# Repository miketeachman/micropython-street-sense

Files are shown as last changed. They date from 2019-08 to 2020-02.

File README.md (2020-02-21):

# Street Sense

Street Sense is a MicroPython based project to build a portable, battery-powered sensor unit to measure: 

- **Air Quality**
    - Ozone
    - NO2 
    - Particulates 
- **Noise Pollution**
- **Environment**
    - Temperature
    - Humidity

## Detailed project documentation:
[Street Sense Project at Hackaday IO](https://hackaday.io/project/162059-street-sense)

## Dependencies
### Hardware 
Lolin D32 Pro  
<https://wiki.wemos.cc/products:d32:d32_pro>
### Micropython
fork of micropython
https://github.com/miketeachman/micropython/tree/esp32-i2s-streetsense-littlevgl
which includes these customizations:
- I2S module to read audio samples from an I2S microphone. [link](https://github.com/miketeachman/micropython/blob/esp32-i2s-streetsense-littlevgl/ports/esp32/machine_i2s.c)
- dba module for calculating dB(A) from a stream of audio samples. [link](https://github.com/miketeachman/micropython/blob/esp32-i2s-streetsense-littlevgl/ports/esp32/moddba.c)  
- i2stools module for efficient copy/pruning of audio samples. [link](https://github.com/miketeachman/micropython/blob/esp32-i2s-streetsense-littlevgl/ports/esp32/modi2stools.c)
- integration of littlevGL graphics library. [link](https://github.com/miketeachman/lv_binding_micropython/tree/lvgl-streetsense)

### MicroPython Modules

| name|link|
|---- | ----- |
|asyn | https://github.com/peterhinch/micropython-async/blob/master/asyn.py  |
|aswitch | https://github.com/peterhinch/micropython-async/blob/master/aswitch.py |
|uasyncio (fast\_io) | https://github.com/peterhinch/micropython-async/tree/master/fast_io  |
|ms\_timer| https://github.com/peterhinch/micropython-async/blob/master/fast_io/ms_timer.py |
|pms5003: | https://github.com/miketeachman/micropython-pms5003-minimal | 
|urtc: | https://github.com/adafruit/Adafruit-uRTC |
|ads1219: | https://github.com/miketeachman/micropython-ads1219|
|si7021:  | https://github.com/chrisbalmer/micropython-si7021|
|mqtt\_as:| https://github.com/kevinkk525/micropython-mqtt/tree/pause_resume|
|logging: | https://github.com/micropython/micropython-lib/tree/master/logging|

### MicroPython Libs
fork of littlevgl graphics library with customizations
https://github.com/miketeachman/lv_binding_micropython/commits/lvgl-streetsense

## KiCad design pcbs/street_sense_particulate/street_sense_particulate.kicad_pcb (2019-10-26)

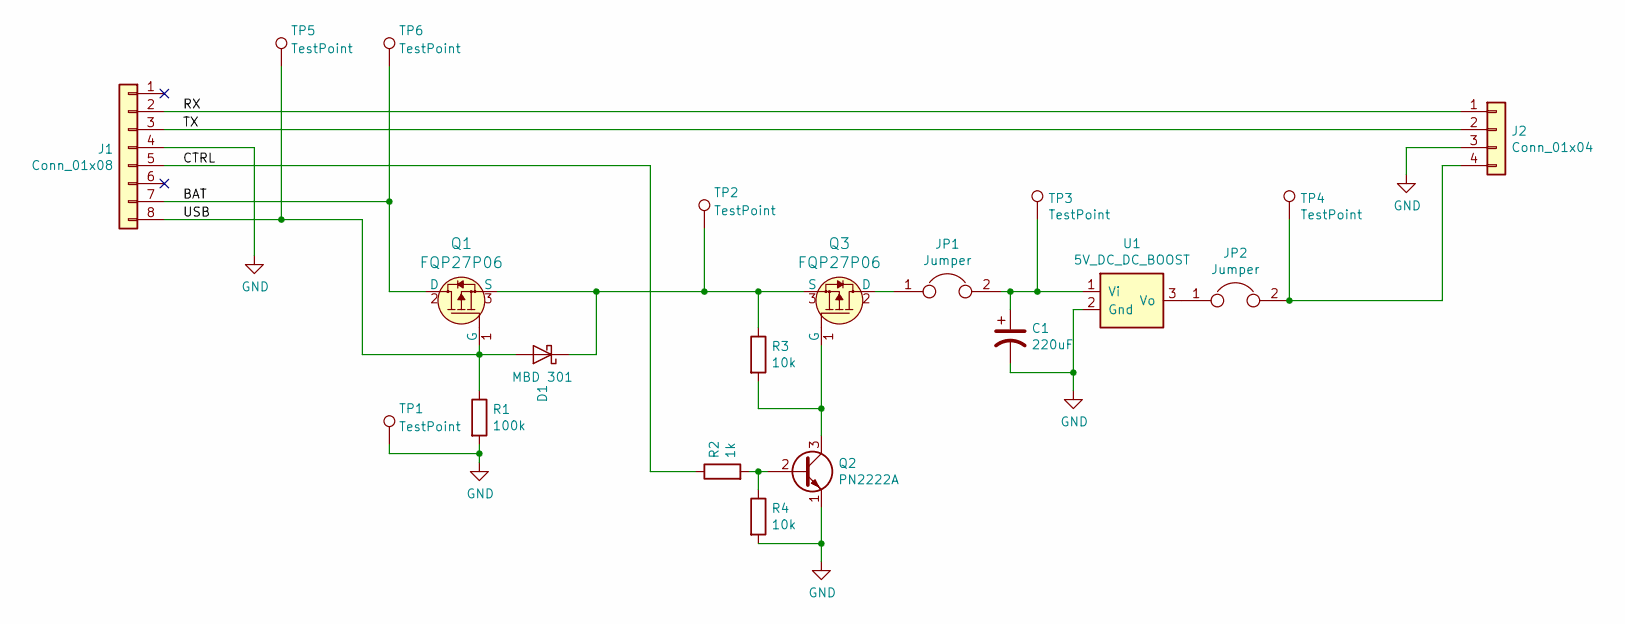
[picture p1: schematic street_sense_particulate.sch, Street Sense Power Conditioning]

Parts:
C1: 220uF; CP_Radial_D5.0mm_P2.50mm
D1: MBD 301; D_A-405_P5.08mm_Vertical_AnodeUp
J1: Conn_01x08; PinHeader_1x08_P2.54mm_Vertical
J2: Conn_01x04; PinHeader_1x04_P2.54mm_Vertical
JP1, JP2: Jumper; SolderJumper-2_P1.3mm_Open_Pad1.0x1.5mm
Q1, Q3: FQP27P06; TO-220-3; MPN FQP27P06; Digi-Key_PN FQP27P06-ND
Q2: PN2222A; TO-92-3_Formed_Leads
R1: 100k; R_Axial_DIN0207_L6.3mm_D2.5mm_P10.16mm_Horizontal
R2: 1k; R_Axial_DIN0207_L6.3mm_D2.5mm_P10.16mm_Horizontal
R3: 10k; R_Axial_DIN0309_L9.0mm_D3.2mm_P12.70mm_Horizontal
R4: 10k; R_Axial_DIN0204_L3.6mm_D1.6mm_P2.54mm_Vertical
TP1, TP2, TP3, TP4, TP5, TP6: TestPoint; TestPoint_Loop_D2.50mm_Drill1.0mm
U1: 5V_DC_DC_BOOST; TO-220-3

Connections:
/BAT: J1.7, Q1.2 (D), TP6.1
/CTRL: J1.5, R2.1
/RX: J1.2, J2.1
/TX: J1.3, J2.2
/USB: D1.2 (A), J1.8, Q1.1 (G), R1.1, TP5.1
GND: C1.2, J1.4, J2.3, Q2.1 (E), R1.2, R4.2, TP1.1, U1.2 (Gnd)
unnamed: C1.1, JP1.2, TP3.1, U1.1 (Vi)
unnamed: D1.1 (K), Q1.3 (S), Q3.3 (S), R3.1, TP2.1
unnamed: J2.4, JP2.2, TP4.1
unnamed: JP1.1, Q3.2 (D)
unnamed: JP2.1, U1.3 (Vo)
unnamed: Q2.2 (B), R2.2, R4.1
unnamed: Q2.3 (C), Q3.1 (G), R3.2

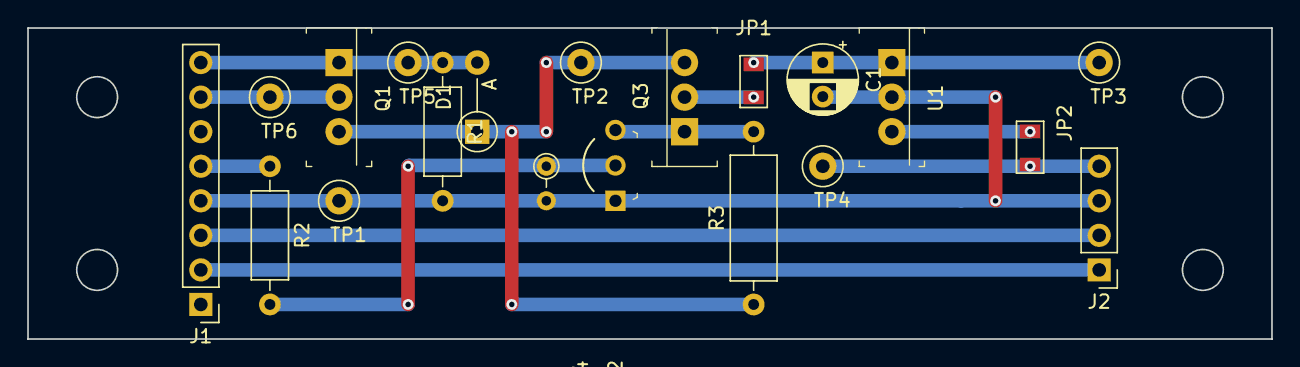
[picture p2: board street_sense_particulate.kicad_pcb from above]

Board: 2 copper layers, 91.4 x 22.9 mm, 20 parts (0 on the bottom side), 13 nets.

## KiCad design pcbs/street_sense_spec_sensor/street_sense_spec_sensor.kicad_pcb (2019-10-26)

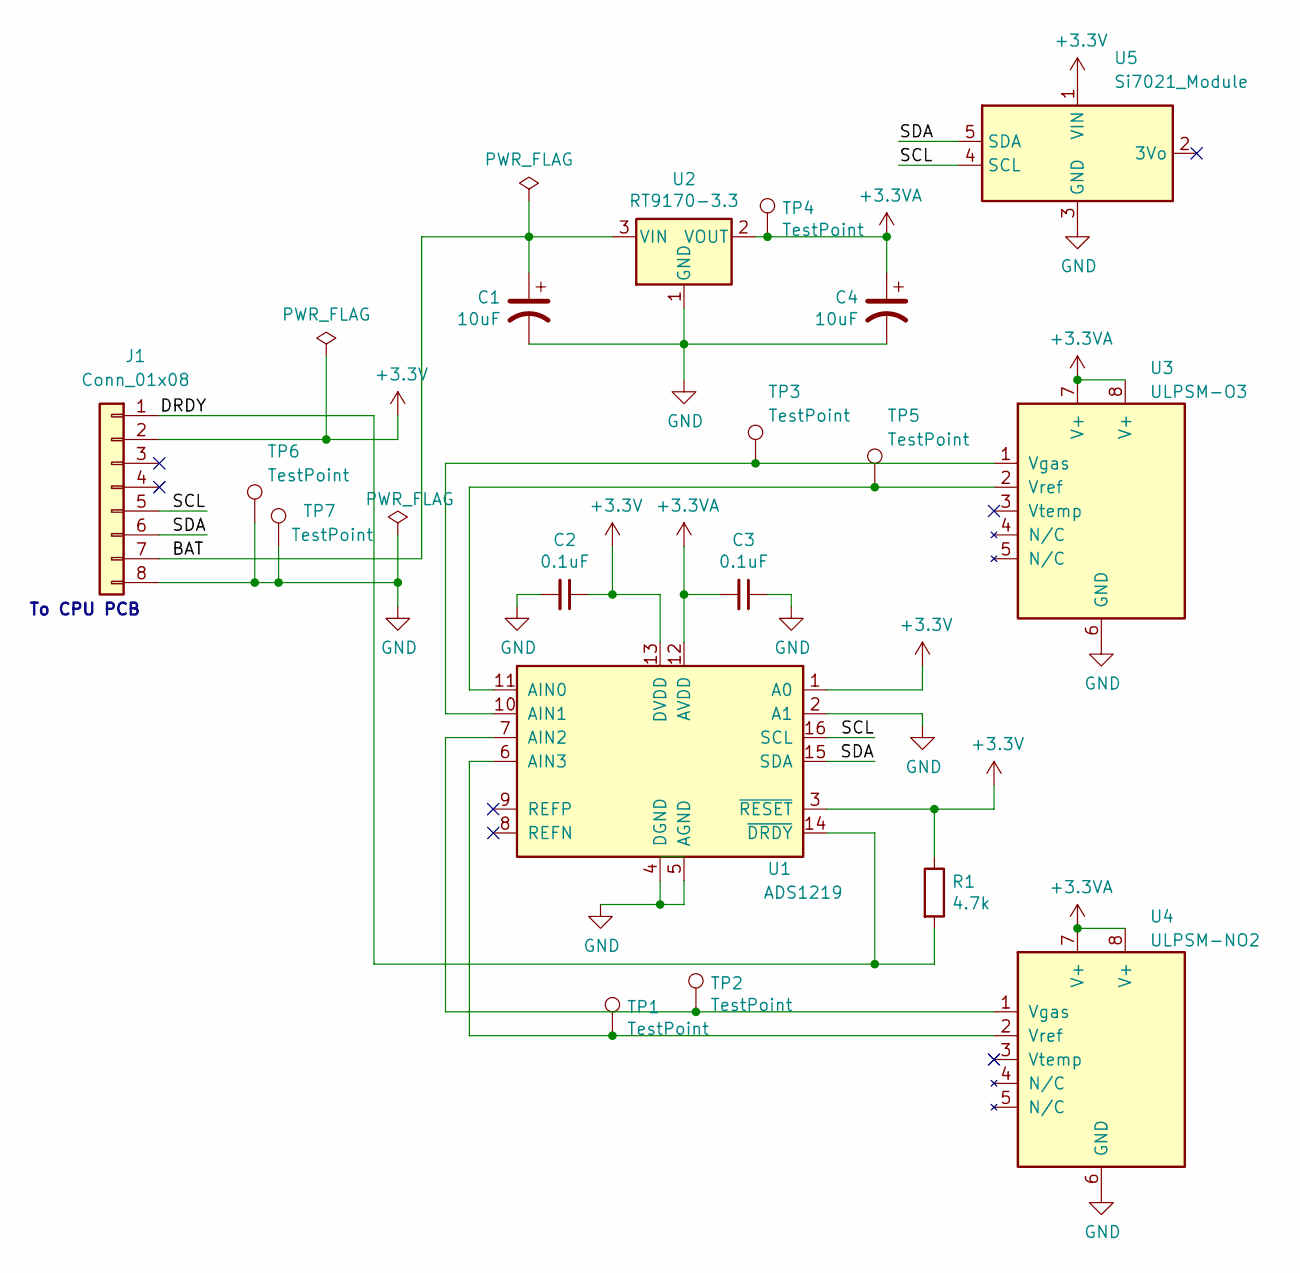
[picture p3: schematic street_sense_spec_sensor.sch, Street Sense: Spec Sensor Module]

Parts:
C1: 10uF; CP_Radial_Tantal_D4.5mm_P2.50mm
C2, C3: 0.1uF; C_Disc_D4.3mm_W1.9mm_P5.00mm
C4: 10uF; CP_Radial_Tantal_D4.5mm_P5.00mm
J1: Conn_01x08; connector_8pin
R1: 4.7k; R_Axial_DIN0204_L3.6mm_D1.6mm_P2.54mm_Vertical
TP1, TP2, TP3, TP4, TP5, TP6, TP7: TestPoint; TestPoint_Loop_D2.50mm_Drill1.0mm
U1: ADS1219; ADS1219_Module
U2: RT9170-3.3; RT9170_Module
U3: ULPSM-O3; Spec_Sensor_ULPSM_Module
U4: ULPSM-NO2; Spec_Sensor_ULPSM_Module
U5: Si7021_Module

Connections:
+3.3VA: C3.2, C4.1, TP4.1, U1.12 (AVDD), U2.2 (VOUT), U3.7 (V+), U3.8 (V+), U4.7 (V+), U4.8 (V+)
+3V3: C2.1, J1.2, R1.1, U1.1 (A0), U1.3 (~RESET), U1.13 (DVDD), U5.1 (VIN)
/BAT: C1.1, J1.7, U2.3 (VIN)
/DRDY: J1.1, R1.2, U1.14 (~DRDY)
/SCL: J1.5, U1.16 (SCL), U5.4 (SCL)
/SDA: J1.6, U1.15 (SDA), U5.5 (SDA)
GND: C1.2, C2.2, C3.1, C4.2, J1.8, TP6.1, TP7.1, U1.2 (A1), U1.4 (DGND), U1.5 (AGND), U2.1 (GND), U3.6 (GND), U4.6 (GND), U5.3 (GND)
unnamed: TP1.1, U1.6 (AIN3), U4.2 (Vref)
unnamed: TP2.1, U1.7 (AIN2), U4.1 (Vgas)
unnamed: TP3.1, U1.10 (AIN1), U3.1 (Vgas)
unnamed: TP5.1, U1.11 (AIN0), U3.2 (Vref)

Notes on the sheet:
To CPU PCB

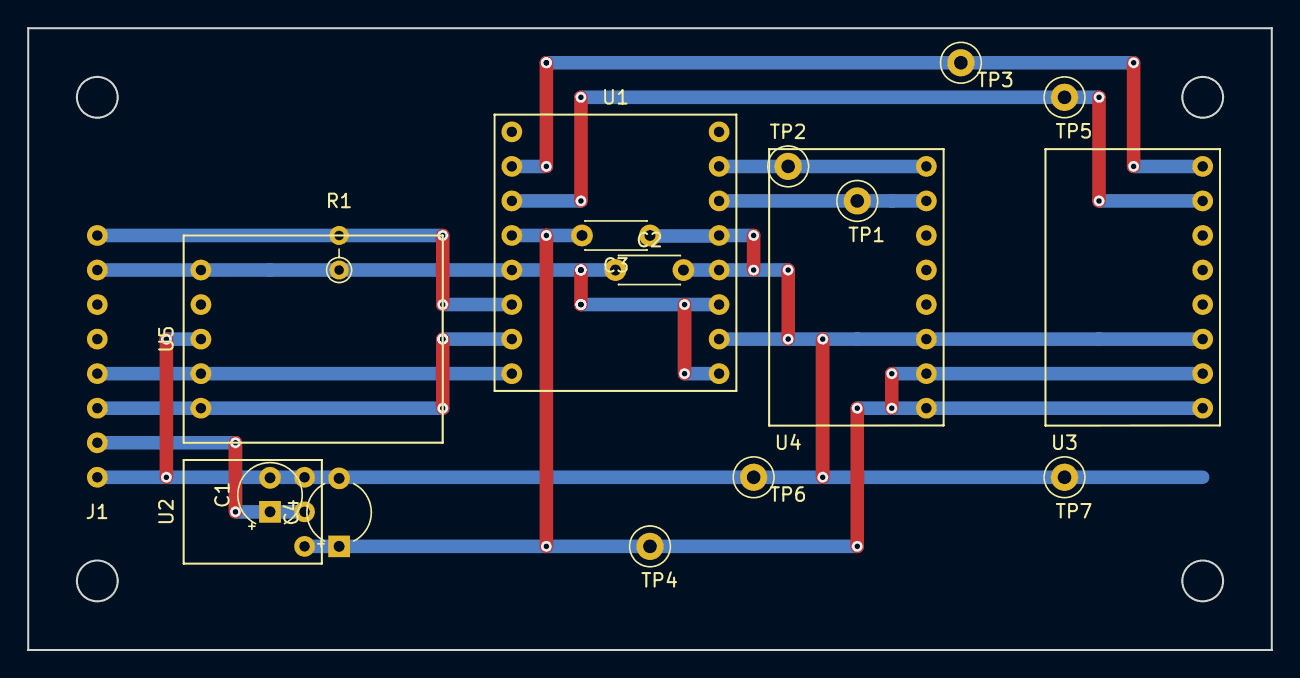
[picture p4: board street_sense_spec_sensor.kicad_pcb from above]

Board: 2 copper layers, 91.4 x 45.7 mm, 18 parts (0 on the bottom side), 11 nets.

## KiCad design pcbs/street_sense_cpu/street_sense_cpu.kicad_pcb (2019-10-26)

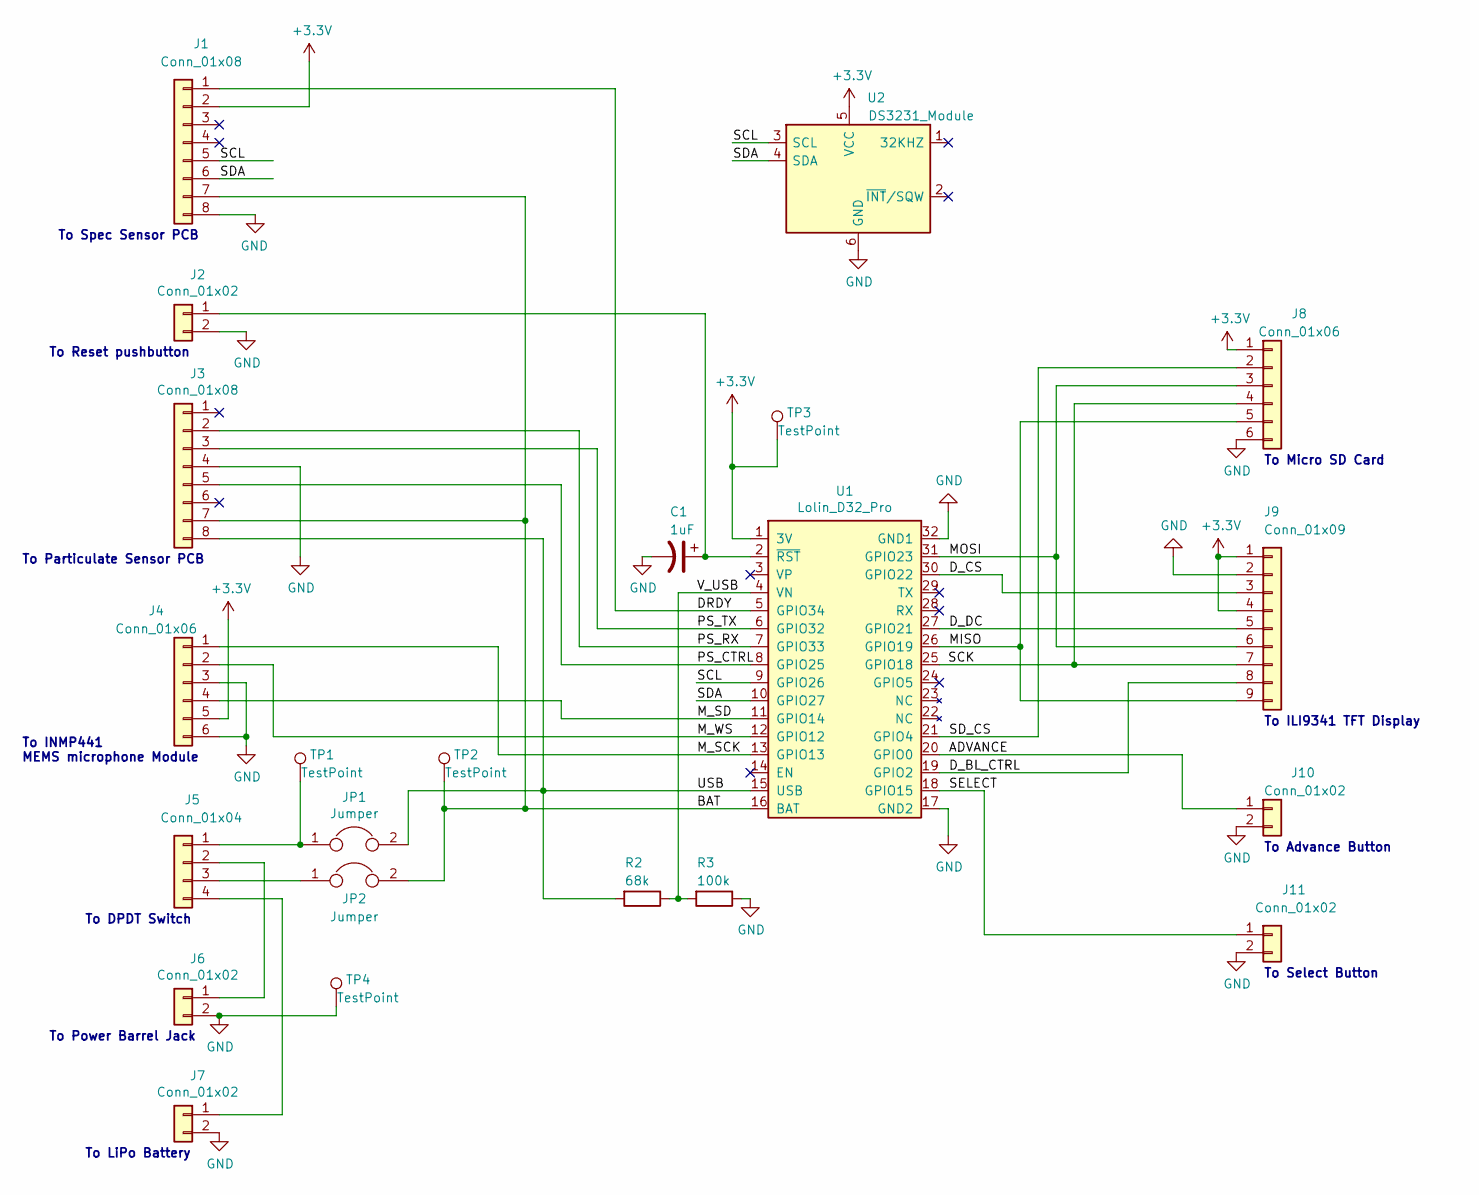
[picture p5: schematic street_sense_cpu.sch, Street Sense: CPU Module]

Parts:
C1: 1uF; CP_Radial_D5.0mm_P2.50mm
J1, J3: Conn_01x08; connector_8pin
J2, J6, J7, J10, J11: Conn_01x02; connector_2pin
J4, J8: Conn_01x06; connector_6pin
J5: Conn_01x04; connector_4pin
J9: Conn_01x09; connector_9pin
JP1, JP2: Jumper; SolderJumper-2_P1.3mm_Open_Pad1.0x1.5mm
R2: 68k; R_Axial_DIN0207_L6.3mm_D2.5mm_P7.62mm_Horizontal
R3: 100k; R_Axial_DIN0207_L6.3mm_D2.5mm_P7.62mm_Horizontal
TP1, TP2, TP3, TP4: TestPoint; TestPoint_Loop_D2.50mm_Drill1.0mm
U1: Lolin_D32_Pro; LolinD32
U2: DS3231_Module

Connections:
+3V3: J1.2, J4.5, J8.1, J9.1, J9.4, TP3.1, U1.1 (3V), U2.5 (VCC)
/ADVANCE: J10.1, U1.20 (GPIO0)
/BAT: J1.7, J3.7, JP2.2, TP2.1, U1.16 (BAT)
/DRDY: J1.1, U1.5 (GPIO34)
/D_BL_CTRL: J9.8, U1.19 (GPIO2)
/D_CS: J9.3, U1.30 (GPIO22)
/D_DC: J9.5, U1.27 (GPIO21)
/MISO: J8.5, J9.9, U1.26 (GPIO19)
/MOSI: J8.3, J9.6, U1.31 (GPIO23)
/M_SCK: J4.1, U1.13 (GPIO13)
/M_SD: J4.4, U1.11 (GPIO14)
/M_WS: J4.2, U1.12 (GPIO12)
/PS_CTRL: J3.5, U1.8 (GPIO25)
/PS_RX: J3.2, U1.7 (GPIO33)
/PS_TX: J3.3, U1.6 (GPIO32)
/SCK: J8.4, J9.7, U1.25 (GPIO18)
/SCL: J1.5, U1.9 (GPIO26), U2.3 (SCL)
/SDA: J1.6, U1.10 (GPIO27), U2.4 (SDA)
/SD_CS: J8.2, U1.21 (GPIO4)
/SELECT: J11.1, U1.18 (GPIO15)
/USB: J3.8, JP1.2, R2.2, U1.15 (USB)
/V_USB: R2.1, R3.2, U1.4 (VN)
GND: C1.2, J1.8, J2.2, J3.4, J4.3, J4.6, J6.2, J7.2, J8.6, J9.2, J10.2, J11.2, R3.1, TP4.1, U1.17 (GND2), U1.32 (GND1), U2.6 (GND)
unnamed: C1.1, J2.1, U1.2 (~RST)
unnamed: J5.1, JP1.1, TP1.1
unnamed: J5.2, J6.1
unnamed: J5.3, JP2.1
unnamed: J5.4, J7.1

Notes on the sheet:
To INMP441 MEMS microphone Module
To Particulate Sensor PCB
To Reset pushbutton
To LiPo Battery
To Power Barrel Jack
To Micro SD Card
To ILI9341 TFT Display
To Advance Button
To Select Button
To Spec Sensor PCB
To DPDT Switch

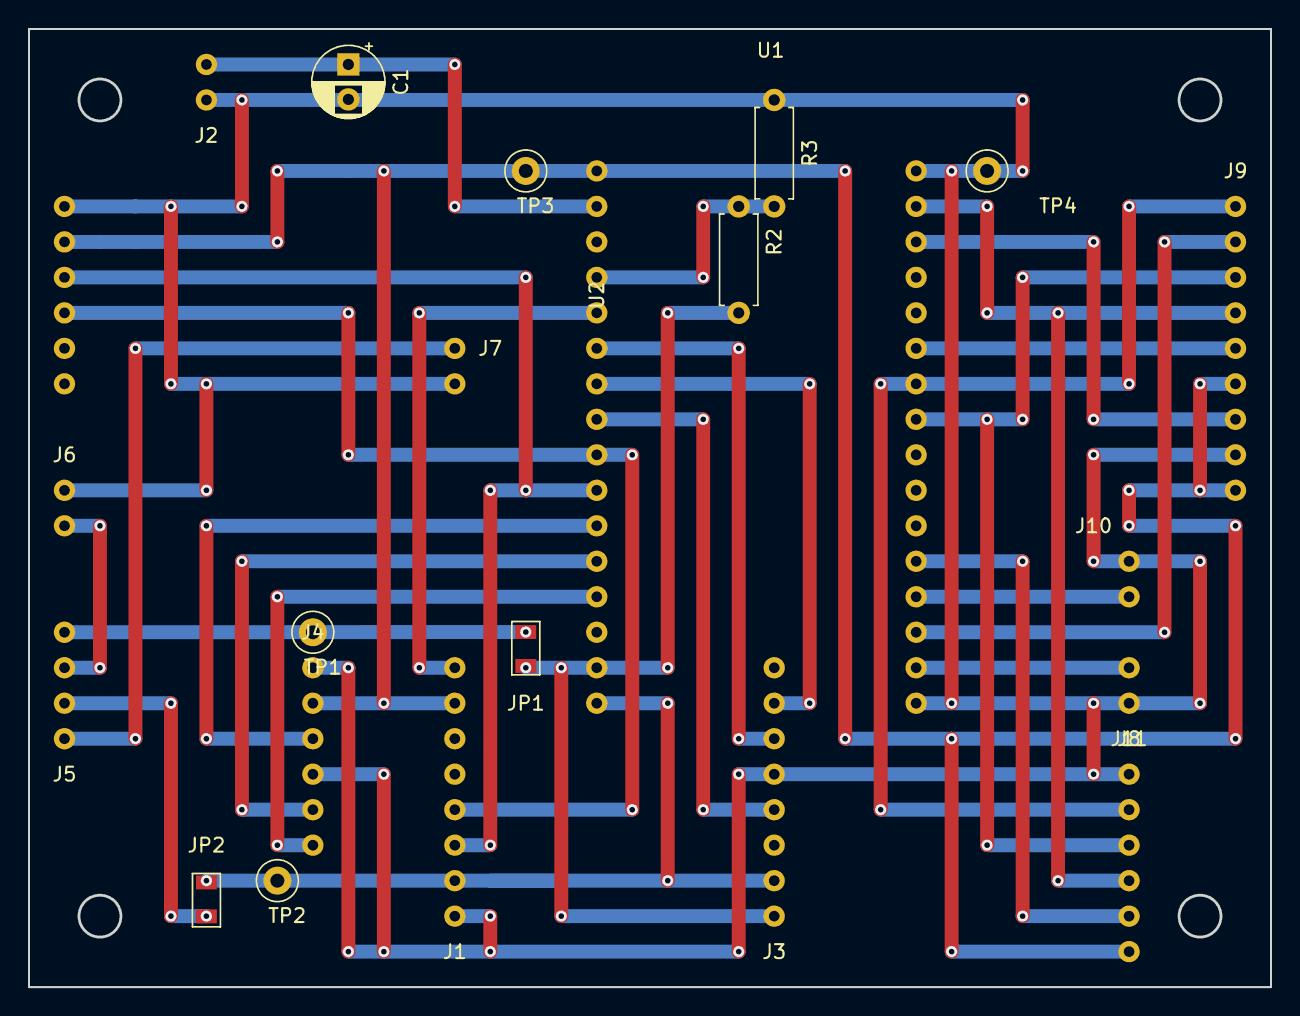
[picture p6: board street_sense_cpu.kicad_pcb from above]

Board: 2 copper layers, 88.9 x 68.6 mm, 22 parts (0 on the bottom side), 28 nets.

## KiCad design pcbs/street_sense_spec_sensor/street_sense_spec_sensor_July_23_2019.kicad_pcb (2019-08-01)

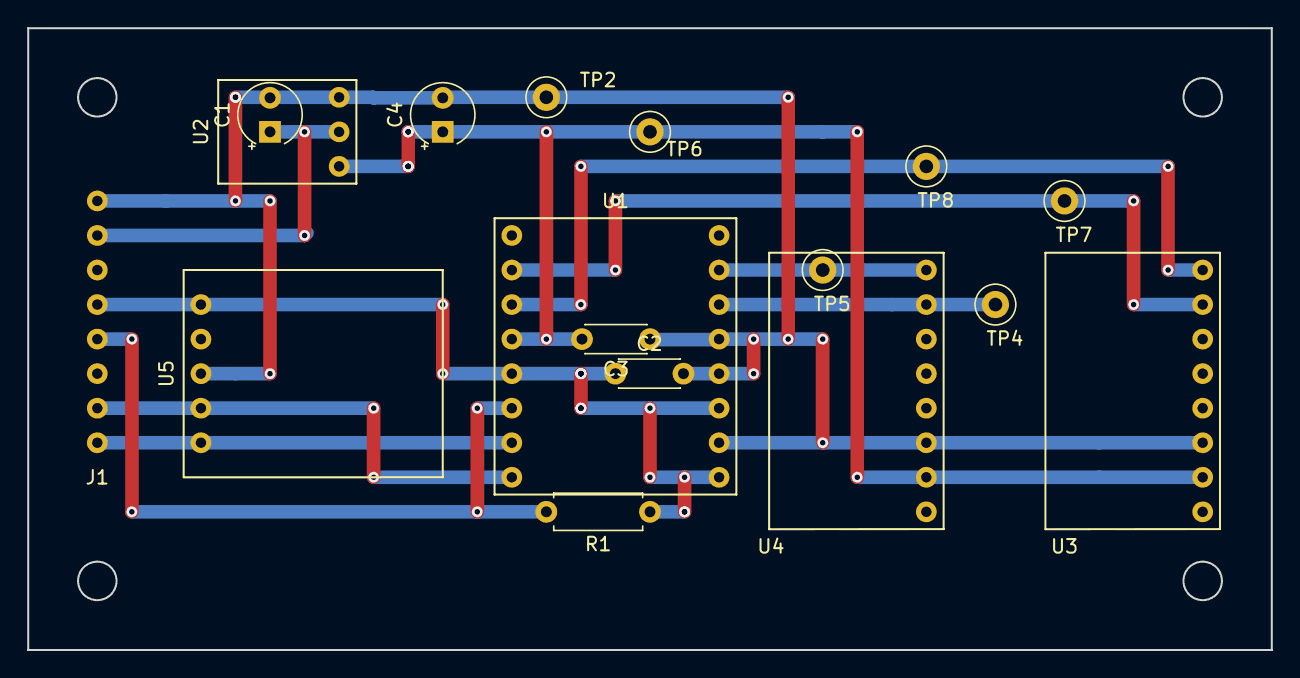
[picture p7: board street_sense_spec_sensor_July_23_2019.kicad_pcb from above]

Board: 2 copper layers, 91.4 x 45.7 mm, 17 parts (0 on the bottom side), 11 nets.

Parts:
C1, C4: 10uF; CP_Radial_Tantal_D4.5mm_P2.50mm
C2, C3: 0.1uF; C_Disc_D4.3mm_W1.9mm_P5.00mm
J1: Conn_01x08; connector_8pin
R1: 4.7k; R_Axial_DIN0207_L6.3mm_D2.5mm_P7.62mm_Horizontal
TP2, TP4, TP5, TP6, TP7, TP8: TestPoint; TestPoint_Loop_D2.50mm_Drill1.0mm
U1: ADS1219; ADS1219_Module
U2: RT9170-3.3; RT9170_Module
U3: ULPSM-O3; Spec_Sensor_ULPSM_Module
U4: ULPSM-NO2; Spec_Sensor_ULPSM_Module
U5: Si7021_Module

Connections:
+3.3VA: C3.2, C4.1, TP6.1, U1.12, U2.2, U3.7, U4.7
+3V3: C2.1, J1.4, R1.1, U1.1, U1.3, U1.13, U5.1
/BAT: C1.1, J1.2, U2.3
/DRDY: J1.5, R1.2, U1.14
/SCL: J1.7, U1.16, U5.4
/SDA: J1.8, U1.15, U5.5
GND: C1.2, C2.2, C3.1, C4.2, J1.1, TP2.1, U1.2, U1.4, U1.5, U2.1, U3.6, U4.6, U5.3
unnamed: TP4.1, U1.6, U4.2
unnamed: TP5.1, U1.7, U4.1
unnamed: TP7.1, U1.10, U3.2
unnamed: TP8.1, U1.11, U3.1

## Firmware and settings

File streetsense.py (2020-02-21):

# The MIT License (MIT)
# Copyright (c) 2020 Mike Teachman
# https://opensource.org/licenses/MIT

#
# Street Sense Project:  Air and Noise pollution sensor unit
# https://hackaday.io/project/162059-street-sense
#
import gc
import sys
import esp
import math
import machine
from machine import I2S
from machine import I2C
from machine import Pin
from machine import UART
from machine import SDCard
from machine import ADC
from machine import Timer
from array import array
import uos
import utime
from mqtt_as import MQTTClient
from mqtt_config import mqtt_config
import uasyncio as asyncio
from aswitch import Pushbutton
import asyn
import ms_timer
import logging
from ads1219 import ADS1219
import lvgl as lv
import ILI9341 as ili
import lvesp32
import pms5003
import urtc
import si7021
import i2stools
import dba
import wavheader
from collections import namedtuple
#import fft
#import ustruct

###################################
#    GPIO Pin Allocation
###################################
#
#    SPI Devices
#    - Micro SD Card
#    - ILI9341 display
# 
#    Shared SPI Connections
#    Pin   Function
#    18    SCK
#    19    MISO
#    23    MOSI

#    Micro SD Card
#    4     CS

#    ILI9341 Display
#    Pin   Function
#    22    CS
#    21    DC
#    2     LED backlight control

#    UART Device
#    - PMS5003 Particulate Sensor
#
#    UART Connections
#    Pin   Function
#    32    Tx
#    33    Rx
#
#    Particulate Sensor Power Control
#    Pin   Function
#    25    Pwr on/off

#    I2C Devices
#    - DS3231 Real Time Clock (address = 0x68)
#    - ADS1219 24-bit ADC (address = 0x41)
#    - si7021 Temp/Humidity sensor (address = 0x40 )
#    
#    I2C Connections
#    Pin   Function
#    27    SDA
#    26    SCL

#    ADS1219 ADC
#    Pin   Function
#    34    DRDY

#    I2S Device
#    - INMP441 omnidirectional MEMS microphone
#
#    I2S Connections
#    Pin   Function
#    13    SCK
#    12    WS
#    14    SD
#  
#    Push Buttons
#    Pin   Function
#    0     Advance
#    15    Select

#    Analog Inputs
#    35    Battery Voltage. Resistive divider on Lolin board: BAT-100k-Pin35-100k-GND
#    39    USB Voltage. Resistive divider:  USB-68k-Pin39-100k-GND

#    UNUSED GPIO PINS
#    5
#    36

LOGGING_INTERVAL_IN_SECS = 60*2

# I2S Microphone related config
# TODO:  refactor this section to improve reader comprehension
SAMPLES_PER_SECOND = 10000
RECORD_TIME_IN_SECONDS = 20
NUM_BYTES_RX = 8
NUM_BYTES_USED = 2  
BITS_PER_SAMPLE = NUM_BYTES_USED * 8
NUM_BYTES_IN_SDCARD_SECTOR = 512
NUM_BYTES_IN_SAMPLE_BLOCK = NUM_BYTES_IN_SDCARD_SECTOR * (NUM_BYTES_RX // NUM_BYTES_USED)
NUM_SAMPLE_BYTES_IN_WAV = (RECORD_TIME_IN_SECONDS * SAMPLES_PER_SECOND * NUM_BYTES_USED)
NUM_SAMPLE_BYTES_TO_RX = ((RECORD_TIME_IN_SECONDS * SAMPLES_PER_SECOND * NUM_BYTES_RX))

DEMO_MODE = 1
NORMAL_MODE = 2
Mode = namedtuple('Mode', 'aq display logging mqtt')
modes = {DEMO_MODE:Mode(aq='continuous', display='always_on', logging=0, mqtt=0),
         NORMAL_MODE:Mode(aq='periodic', display="timeout", logging=1, mqtt=1)}

PM_POLLING_DELAY_MS = 500

# convert a timestamp (in seconds) from MicroPython epoch to Unix epoch
# from uPy docs:  "However, embedded ports use epoch of 2000-01-01 00:00:00 UTC"
# Unix time epoch is 1970-01-01 00:00:00 UTC
def epoch_time_upy_to_unix(upy_time):
    return upy_time + 946684800

# convert a timestamp (in seconds) from GMT to Pacific Standard Time (PST)
# no support for DST
def gmt_to_pst(gmt_time):
    return gmt_time - (3600 * 8)

#
# Measurement Repository
# - stores current value of measurements
# - calculates stats: min, max, sum, avg, count
#
class MeasurementRepo():
    Measurement = namedtuple('Measurement', 'current min max sum avg count')
    
    def __init__(self):
        log.info('REPO:init')
        self.measurement_repo = {}

    def add(self, measurement, value):
        log.debug('REPO:add')
        if not measurement in self.measurement_repo:
            self.measurement_repo[measurement] = MeasurementRepo.Measurement(current=None, min=None, max=None, sum=0, avg=0, count=0)
    
        min =  self.measurement_repo[measurement].min
        if min is None or value < min:
            min = value
            
        max =  self.measurement_repo[measurement].max  
        if max is None or value > max:
            max = value
            
        sum = self.measurement_repo[measurement].sum + value
        count = self.measurement_repo[measurement].count + 1
        avg = sum / count
            
        self.measurement_repo[measurement] = MeasurementRepo.Measurement(current=value, min=min, max=max, sum=sum, avg=avg, count=count)
            
    def get(self, measurement):
        log.debug('REPO:get')
        if measurement in self.measurement_repo:
            return self.measurement_repo[measurement]
        else:
            return MeasurementRepo.Measurement(current=0, min=0, max=0, sum=0, avg=0, count=0)  
        
    def clear_stats(self, measurement):    
        log.debug('REPO:clear')
        if measurement in self.measurement_repo:
            value =  self.measurement_repo[measurement].current
        self.measurement_repo[measurement] = MeasurementRepo.Measurement(current=value, min=None, max=None, sum=0, avg=0, count=0)

# TODO pass in ADC object
class SpecSensors():
    SAMPLES_TO_CAPTURE = 100
    CALIBRATION_FACTOR_OZONE = (-21.7913*(10**-3))  # mV/ppb
    CALIBRATION_FACTOR_NO2 = (-11.13768*(10**-3))   # mV/ppb
                          
    def __init__(self):
        log.info('SPEC:init')
        self.sample_count = 0
        self.sample_sum = 2**32-1   # allocate 4 byte sample to be used in ISR  TODO needed?

        adc.set_channel(ADS1219.CHANNEL_AIN0)
        adc.set_conversion_mode(ADS1219.CM_SINGLE)
        adc.set_gain(ADS1219.GAIN_1X)
        adc.set_data_rate(ADS1219.DR_20_SPS)
        adc.set_vref(ADS1219.VREF_INTERNAL)
        self.drdy_pin = Pin(34, mode=Pin.IN)        
        
    def callback(self, arg):
        if self.sample_count < self.SAMPLES_TO_CAPTURE:
            self.sample_sum += adc.read_data_irq()
            self.sample_count += 1
        
    async def read(self, adc_channel):
        log.info('SPEC:read adc_channel= %d', adc_channel)
        self.sample_sum= 0 
        self.sample_count = 0     
        adc.set_channel(adc_channel)
        adc.set_conversion_mode(ADS1219.CM_CONTINUOUS)
        adc.set_gain(ADS1219.GAIN_1X)
        adc.set_data_rate(ADS1219.DR_20_SPS)
        adc.set_vref(ADS1219.VREF_INTERNAL)
        adc.start_sync() # starts continuous sampling
        start_capture = utime.ticks_ms()
        # enable interrupts
        self.drdy_pin.irq(trigger=Pin.IRQ_FALLING, handler=self.callback)
        
        while self.sample_count < self.SAMPLES_TO_CAPTURE:
            await asyncio.sleep_ms(10)

        # disable the interrupt by setting handler = None
        self.drdy_pin.irq(handler = None)
        log.debug('SPEC:done.  conversion time = %d', utime.ticks_diff(utime.ticks_ms(), start_capture))
        adc.set_conversion_mode(ADS1219.CM_SINGLE)
        
        avg_mv = self.sample_sum * ADS1219.VREF_INTERNAL_MV / ADS1219.POSITIVE_CODE_RANGE / self.sample_count
        log.debug('SPEC:avg_mv = %d', avg_mv)
        
        return avg_mv
    
    async def read_all(self):
        # read Ozone gas voltage
        repo.add('o3_vgas', await self.read(ADS1219.CHANNEL_AIN1))        
        # read Ozone reference voltage
        repo.add('o3_vref', await self.read(ADS1219.CHANNEL_AIN0))       
        # read NO2 gas voltage
        repo.add('no2_vgas', await self.read(ADS1219.CHANNEL_AIN2))        
        # read NO2 reference voltage
        repo.add('no2_vref', await self.read(ADS1219.CHANNEL_AIN3))      
        
        # calculate gas concentration in parts-per-billion (ppb)
        # TODO investigate differential ADC calc
        # TODO calibrate Spec Sensors, with offset
        ozone_ppb = (repo.get('o3_vgas').current - repo.get('o3_vref').current) / self.CALIBRATION_FACTOR_OZONE
        repo.add('o3', ozone_ppb)
        no2_ppb = (repo.get('no2_vgas').current - repo.get('no2_vref').current) / self.CALIBRATION_FACTOR_NO2
        repo.add('no2', no2_ppb)

# TODO does this class make sense anymore ?        
class THSensor():
    def __init__(self):
        log.info('TH:init')
        loop = asyncio.get_event_loop()
        loop.create_task(self.run_th_continuous())
        
    async def run_th_continuous(self):
        while True:
            repo.add('tdegc', temp_humid_sensor.temperature)
            repo.add('rh', temp_humid_sensor.relative_humidity)
            await asyncio.sleep(1)

    async def read(self):
        repo.add('tdegc', temp_humid_sensor.temperature)
        repo.add('rh', temp_humid_sensor.relative_humidity)

class ParticulateSensor():
    def __init__(self, 
                 lock, 
                 event_new_pm_data):
        log.info('PM:init')
        self.lock = lock
        self.event_new_pm_data = event_new_pm_data
        self.uart = None
        self.pm = None
        self.pm_pwr_pin = Pin(25, Pin.OUT)
        if modes[operating_mode].aq == 'continuous':
            loop = asyncio.get_event_loop()
            loop.create_task(self.run_pm_continuous())
        else:
            self.pm_pwr_pin.value(0)
        
    async def read_pm(self):
        log.info('PM:30s warm-up')
        self.pm_pwr_pin.value(1)
        await asyncio.sleep(30) # 30s warm-up period as specified in datasheet
        self.uart = UART(1, tx=32, rx=33, baudrate=9600)
        self.pm = pms5003.PMS5003(self.uart, self.lock, event = self.event_new_pm_data)
        await asyncio.sleep(1)
        log.debug('PM:set Passive mode')
        await self.pm.setPassiveMode()
        log.debug('PM:trigger read sensor')
        await asyncio.sleep(1)
        await self.pm.read()
        log.debug('PM:waiting for event')
        await self.event_new_pm_data
        log.debug('PM:got event')
        repo.add('pm10', self.pm.pm10_env)
        repo.add('pm25', self.pm.pm25_env)
        repo.add('pm100', self.pm.pm100_env)
        log.info('PM:PM2.5 = %d', repo.get('pm25').current)
        self.event_new_pm_data.clear() 
        Pin(32, Pin.IN, Pin.PULL_DOWN)
        Pin(33, Pin.IN, Pin.PULL_DOWN)
        log.info('PM:power-down')
        self.pm_pwr_pin.value(0)
        
    async def run_pm_continuous(self):
        log.info('PM:30s warm-up')
        self.pm_pwr_pin.value(1)
        await asyncio.sleep(30) # 30s warm-up period as specified in datasheet
        self.uart = UART(1, tx=32, rx=33, baudrate=9600)
        self.pm = pms5003.PMS5003(self.uart, self.lock, event = self.event_new_pm_data)
        while True:
            await asyncio.sleep(1)
            log.debug('PM:set Passive mode')
            await self.pm.setPassiveMode()
            log.debug('PM:trigger read sensor')
            await asyncio.sleep(1)
            await self.pm.read()
            log.debug('PM:waiting for event')
            await self.event_new_pm_data
            log.debug('PM:got event')
            repo.add('pm10', self.pm.pm10_env)
            repo.add('pm25', self.pm.pm25_env)
            repo.add('pm100', self.pm.pm100_env)
            log.debug('PM:PM2.5 = %d', repo.get('pm25').current)
            self.event_new_pm_data.clear() 
            await asyncio.sleep(0)
    '''    
    # TODO method needed anymore ?    
    async def get_value(self):
        return self.pm.pm25_env
    '''
class IntervalTimer():
    def __init__(self, event_mqtt_publish):  
        log.info('TMR:init')
        self.event_mqtt_publish = event_mqtt_publish
        loop = asyncio.get_event_loop()
        loop.create_task(self.run_timer()) 
    
    async def run_timer(self):
        global timestamp_unix  # TODO fix this when interval timer becomes a class
        ds3231.alarm(False, alarm=0)  # TODO fix this coupling
        while True:
            time_now = urtc.tuple2seconds(ds3231.datetime())
            
            # calculate the next alarm time, aligned to the desired interval
            # e.g.  interval=15mins ==>  align to 00, 15, 30, 45 mins
            time_now += 5  # eliminate risk of timing hazard close to interval boundary
            wake_time = ((time_now // LOGGING_INTERVAL_IN_SECS) + 1 ) * LOGGING_INTERVAL_IN_SECS
            
            # set day-of-week (4th element) to None so alarm uses day-of-month (urtc module API requirement)
            # some gymnastics needed ...
            wake_time_tuple = urtc.seconds2tuple(int(wake_time))
            wake_time_list = list(wake_time_tuple)
            wake_time_list[3]=None  
            ds3231.alarm_time(wake_time_list, alarm=0)  # TODO fix coupling   
            log.info('TMR:next sensor read at %s', wake_time_list)
            log.info('TMR:waiting for DS3231 alarm')
            # loop until the DS3231 alarm is detected 
            while ds3231.alarm(alarm=0) == False:
                await asyncio.sleep_ms(250)

            timestamp_unix = epoch_time_upy_to_unix(urtc.tuple2seconds(ds3231.datetime()))
            # clear alarm    
            ds3231.alarm(False, alarm=0)
            log.info('TMR:DS3231 alarm -> read all sensors')
            # dispatch a whole pile of activity
            # following sequence is deliberately sequential so PM2.5 sensor is powered off when
            # the Spec Sensor devices are being read
            await ps.read_pm()
            await spec_sensors.read_all()
            await temp_hum.read()
            await sdcard_logger.run_logger()
            if modes[operating_mode].mqtt == 1:
                self.event_mqtt_publish.set()
            mem_free_before_gc = gc.mem_free()
            log.debug('TMR:gc mem_free = %d bytes', mem_free_before_gc)
            gc.collect()
            log.debug('TMR:gc freed %d bytes', gc.mem_free() - mem_free_before_gc)

class Display():
    SCREEN_TIMEOUT_IN_S = 60*5
    SCREEN_REFRESH_IN_S = 1
    
    def __init__(self):
        log.info('DISP:init')
        self.screens = [self.show_measurement_screen, 
                        self.show_decibel_screen, 
                        self.show_environmental_screen,                        
                        self.show_voltage_monitor_screen,
                        self.show_display_sleep_screen]
        pin_screen = Pin(0, Pin.IN, Pin.PULL_UP)
        pb_screen = Pushbutton(pin_screen)
        pb_screen.press_func(self.next_screen)
        self.active_screen = 1  # TODO make some sort of datastructure for screens + screen ids
        self.next_screen = 0 # show the measurement screen first TODO this is a clunky way to show this after measurement screen
        self.diag_count = 0
        self.screen_timeout = False
        self.timeout_timer = Timer(-1)
        self.backlight_ctrl = Pin(2, Pin.OUT)
        self.backlight_ctrl.value(0)
        loop = asyncio.get_event_loop()
        loop.create_task(self.run_display()) 
        
    # TODO power save mode:
    # - after a timeout, turn backlight off, and send cmd to put display to sleep
        
    async def run_display(self):
        # Initialize the ILI9341 driver
        # spihost:  1=HSPI 2=VSPI
        # Workaround note:  need to initialize the SPI bus before initializing LittlevGL
        # SPI bus init was taken out of LittlevGL for streetsense design...should fix this.  TODO
        # SPI bus initialization is done when the SD Card is initialized 
        # (must be called before display initialization) 
        
        disp = ili.display(spihost=1, miso=19, mosi=23, clk=18, cs=22, dc=21, mhz=25, share=ili.SHARED)
        disp.init()
        
        self.backlight_ctrl.value(0)  # note: init() turns on backlight
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

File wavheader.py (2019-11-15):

def gen_wav_header(
    sampleRate,
    bitsPerSample,
    channels,
    samples,
    ):
    datasize = samples * channels * bitsPerSample // 8
    o = bytes('RIFF', 'ascii')  # (4byte) Marks file as RIFF
    o += (datasize + 36).to_bytes(4, 'little')  # (4byte) File size in bytes excluding this and RIFF marker
    o += bytes('WAVE', 'ascii')  # (4byte) File type
    o += bytes('fmt ', 'ascii')  # (4byte) Format Chunk Marker
    o += (16).to_bytes(4, 'little')  # (4byte) Length of above format data
    o += (1).to_bytes(2, 'little')  # (2byte) Format type (1 - PCM)
    o += channels.to_bytes(2, 'little')  # (2byte)
    o += sampleRate.to_bytes(4, 'little')  # (4byte)
    o += (sampleRate * channels * bitsPerSample // 8).to_bytes(4,
            'little')  # (4byte)
    o += (channels * bitsPerSample // 8).to_bytes(2, 'little')  # (2byte)
    o += bitsPerSample.to_bytes(2, 'little')  # (2byte)
    o += bytes('data', 'ascii')  # (4byte) Data Chunk Marker
    o += datasize.to_bytes(4, 'little')  # (4byte) Data size in bytes
    return o

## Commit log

2018-12-04 Added support for I2S Microphone
    - read a audio sample block from microphone using I2S protocol
    - prune unused data from sample block
    - write samples to WAV file on SD Card
2018-12-18 added I2C device for ozone, no2 sensors
2019-02-08 first version of schematic
    [street_sense.kicad_pcb, street_sense.sch]
2019-02-08 Updated Schematic
    added the following components:
    - Ozone sensor
    - NO2 sensor
    - OLED 128x64 display
    - ADS1015 12-bit ADC
    - DS3231 RTC
    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
    [street_sense.sch]
2019-02-12 added pulldown resistor to I2S microphone
    100k ohm pulldown from DOUT to GND
    as described in manufacturer's datasheet
    [street_sense.sch]
2019-03-15 updated schematic
    added components to reduce power supply rail noise
    created by DC-DC boost converter
    [street_sense.sch]
2019-03-18 integrated ADS1219 ADC into design (code + schematic)
    [street_sense.sch]
2019-03-20 updated uPy code and schematic V06 with new I2S microphone
    Replaced Adafruit SPH0645LM4H I2S microphone with INMP441 I2S microphone
    [street_sense.sch]
2019-03-22 read particulate sensor with Passive mode
2019-03-25 added si7021 temperature/humidity sensor
    - updated uPy code
    - added new symbol to KiCad symbol library
    - updated schematic, v07
    [street_sense.sch]
2019-03-29 publish sensor data to Adafruit IO using Async MQTT
2019-04-06 Publish sensor data with MQTT-AS and improved microphone sample handling
    - new uasyncio task to publish sensor data to Adafruit IO
    - WiFi and MQTT connect ids and passwords stored in a file
    - microphone sampling loop now yields to uasyncio scheduler when DMA memory does
    not contain a complete block of samples.
2019-05-14 Incremental improvements to measurement performance of O3 and NO2 sensors
    Hardware schematic changes:
    - separate 3.3V analog supply for O3, NO2, and ADC components
    - ~DRDY signal to ESP32 GPIO34
    MicroPython changes:
    - ~DRDY signal used with interrupt to read ADC values (replaces I2C polling)
    - average of 100 samples used to calculate Vref and Vgas measurements
    - O3 and NO2 concentrations calculated in parts-per-billion(ppb)
    [street_sense.sch]
2019-06-26 changed to TFT colour display
    - ILI9340 2.2" 240x360
    - asyncio enabled button to switch display screens
2019-08-01 new schematics for CPU and Spec Sensor Modules
    single schematic split into separate CPU and Spec Sensor Modules
    remapping of GPIO pins in MicroPython code to align with the CPU schematic
    [street_sense.kicad_pcb, street_sense.sch, street_sense_cpu.kicad_pcb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]
2019-09-09 updated CPU schematic
    [street_sense_cpu.kicad_pcb, street_sense_cpu.sch]
2019-09-13 added PCB design for power conditioning module
    [street_sense_particulate.kicad_pcb, street_sense_particulate.sch]
2019-10-26 migration to uPy mainline, littlevGL integration
    [street_sense_cpu.kicad_pcb, street_sense_cpu_OLD.sch, street_sense_particulate.kicad_pcb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]
2019-10-28 added voltage monitor for USB and Lipo battery
2019-11-17 updated readme, workaround for sdcard mount() exception
    [streetsense.py]
2019-11-18 optimized handling of ADC interrupts
2019-11-22 fixed bug in calcuation of interval time boundary
    [streetsense.py]
2019-11-30 fixed 2 bugs: clear vusb stats, log dba max not min
    [streetsense.py]
2019-12-08 improved backlight control on startup, show reset cause
    [streetsense.py]
2020-02-21 display buffer optimization, readme correction
    [streetsense.py]

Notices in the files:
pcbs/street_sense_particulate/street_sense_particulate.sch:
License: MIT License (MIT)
